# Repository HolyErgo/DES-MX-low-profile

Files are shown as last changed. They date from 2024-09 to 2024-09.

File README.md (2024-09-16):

# DES keycaps for MX low profile switches with legends

Based on honourable [@pseudoku](https://github.com/pseudoku/)'s [DES](https://github.com/pseudoku/PseudoMakeMeKeyCapProfiles)

Contains 3 rows (R2, R3, R4) and 3 keys for thumbs.
Row keys has tilted version for inner index column.

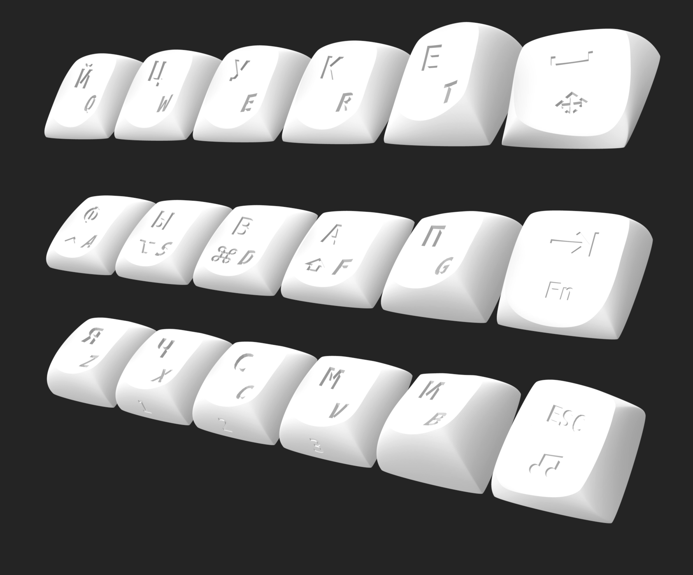
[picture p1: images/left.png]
Whole left side keycaps


### Fits switches:
- Gateron low profile V1 and V2 (KS-27 and KS-33)
- Nuphy low profile
- Keychron low profile optical
- Kailh Choc V2

## OpenSCAD sources

Source code is in `openscad` directory.

`key.scad` generates single keycap.

`generator.scad` contains legends presets for both halfs.

`make_left.scad` and `make_right.scad` generates keycaps in one STL for selected half. 

## How to
Before you start make sure OpenSCAD is up to date.

### Render one keycap
* open `key.scad` in OpenScad
* select keycap you want to render by changing KeyID in `keycap` call
* press F5 to review
* press F6 to render
* press F7 to export as STL

### Legends
If you want to render keycap without legend just set `Legends` parameter to `false`.

All matrix keycaps has defined positions for 2 legends:
1. In top left corner with fontsize 4
2. In bottom right corner with fontsize 3.5

All matrix keycaps except inner index column has 2 extra positions:
3. In bottom left corner with fontsize 3
4. In top right corner with fontsize 3
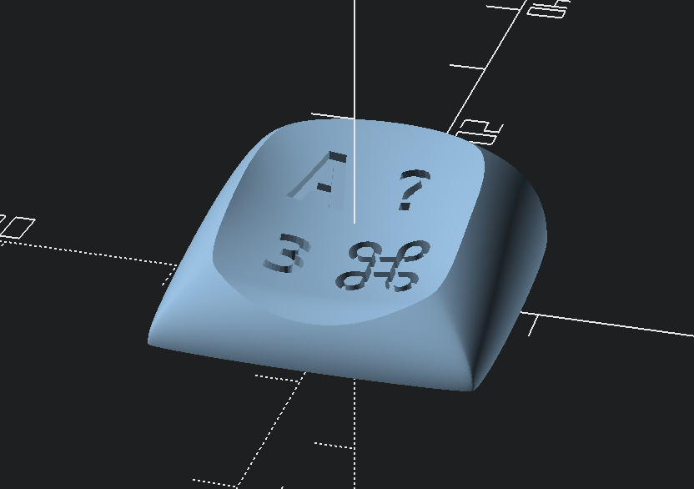
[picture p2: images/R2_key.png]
R2 keycap with 4 legends


Bottom row caps has one extra position on bottom cap side.
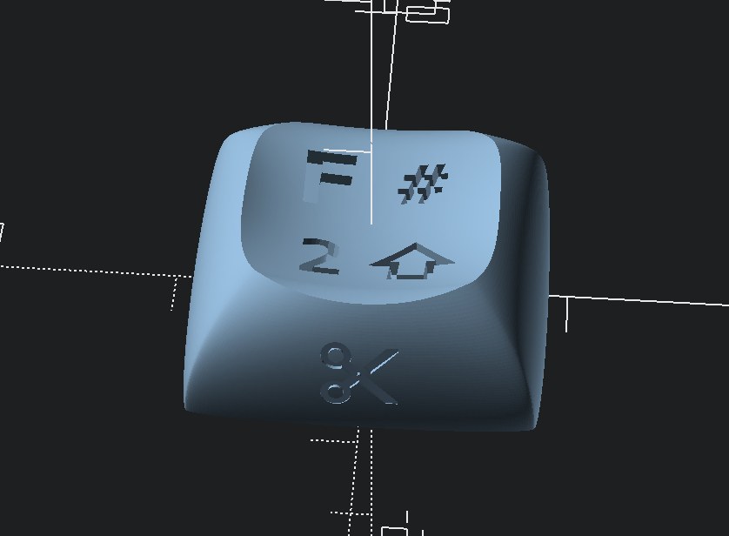
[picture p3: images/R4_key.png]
R4 keycap with 5 legends


Thumbs keycaps has 2 legend positions:
1. On top with fontsize 3
2. On bottom with fontsize 2.5
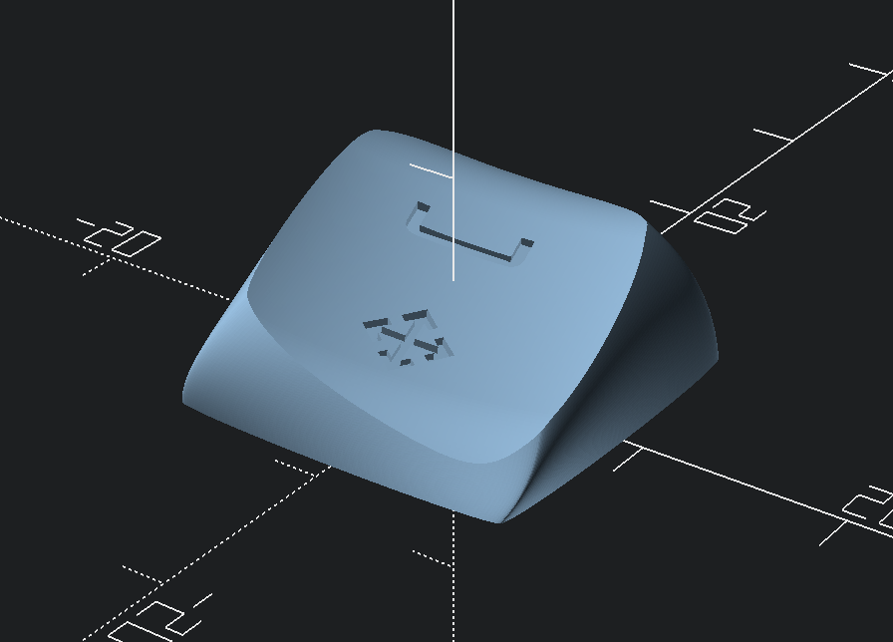
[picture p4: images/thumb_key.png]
Thumbs keycap with 2 legends


To render legends you have to pass them as array in `Legend` parameter. 
```
keycap(
  keyID  = 0, //set keycap
  cutLen = 0, //Don't change. for chopped caps
  Stem   = true, //turn on shell and stems
  Dish   = true, //turn on dish cut
  Stab   = 0, 
  visualizeDish = false, // turn on debug visual of Dish 
  crossSection  = false, // center cut to check internal
  homeDot = false, //turn on homedots
  Legends = ["A",  "command.svg", "3", "!"]
);

```

Each element of legends array may be a symbol, SVG filename or array. Use array as element if you need to specify font size for the legend.
```Legends = ["A", ["shift.svg", 5], ["?", 2.5]]```
You may use empty string for any element to reach next.
```Legends = ["A", "", "", ["?", 2.5]]```

SVG incons are stored in `symbols` directory. If you want to add icons do check paths in svg files. OpenSCAD can't close paths correctly so in some icons you need to do it manually.

Default font for legends is Menlo. It's shipped with MacOS since version 10.13. 

### Render whole half
To render all keycaps for keyboard half in one STL select a preset from `generator.scad` and put it to make-file `make_left.scad` or `make_right.scad`. For examle, to render caps for left half with English Qwerty legends:
```
use <generator.scad>

// Generates all keycaps for left part
generate_part(leftQuerty);
```

Generated STL is useful for resin print. Default parameters allows to print generated STL even on small printers like Elegoo Mars or Anycubic Photon Mono. 

You can change horizontal spacing with `horizontalPitch` variable.
Vertical spacing and X-axis rotation are set in `rows` array.

### Headless rendering
Rendering all keycaps may take a few hours. So a reasonable solution is to render them from command line.

Make sure you put correct preset to make-file before start. Then run rendering in terminal.

```
openscad -o left.stl make_left.scad
```

On Mac you can use full path to OpenSCAD:
```
/Applications/OpenSCAD.app/Contents/MacOS/openscad -o left.stl make_left.scad
```

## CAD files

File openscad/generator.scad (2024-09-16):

use <key.scad>

// 

test = [
  // keys by rows in left to right order
  // ID   Leg1  Leg2 
  [ // R2
    [ 3,   ["Й",  "Q"]],
  ],
  [
    [ 4,   ["Ц",  "W"]],
  ],
  [ // thumbs
    [ 5,   ["W",  "N"]],
  ],
];

/*
 * Preset for keycaps without legends
 */

leftNoLegends = [
  // keys by rows in left to right order
  // ID   Leg1  Leg2  Leg3  Leg4  Leg5
  [ // R2
    [ 0, false],
    [ 0, false],
    [ 0, false],
    [ 0, false],
    [ 3, false],
    [11, false], // inner thumbs
  ],
  [ // R3
    [ 1, false],
    [ 1, false],
    [ 1, false],
    [ 1, false],
    [ 4, false],
    [ 9, false], // home thumbs
  ],
  [ // R4
    [ 2, false],
    [ 2, false],
    [ 2, false],
    [ 2, false],
    [ 5, false],
    [10, false], // outer thumbs
  ],
];

rightNoLegends = [
  // keys by rows in left to right order
  // ID   Leg1  Leg2 
  [ // R2
    [ 6, false],
    [ 0, false],
    [ 0, false],
    [ 0, false],
    [ 0, false],
    [12, false], // outer thumbs
  ],
  [ // R3
    [ 7, false],
    [ 1, false],
    [ 1, false],
    [ 1, false],
    [ 1, false], 
    [ 9, false], // home thumbs
  ],
  [ // R4
    [ 8, false],
    [ 2, false],
    [ 2, false],
    [ 2, false],
    [ 2, false],
    [13, false], // inner thumbs
  ],
];


/*
 * Preset for English Qwerty layout
 * - english symbols are in top left corners of keycaps
 */

leftQuerty = [
  // keys by rows in left to right order
  // ID   Leg1  Leg2  Leg3  Leg4  Leg5
  [ // R2
    [ 0, ["Q"]],
    [ 0, ["W"]],
    [ 0, ["E"]],
    [ 0, ["R"]],
    [ 3, ["T"]],
    [11, [["space.svg", 5],  ["arrows.svg", 3.5]]], // inner thumbs
  ],
  [ // R3
    [ 1, ["A", "control.svg"]],
    [ 1, ["S", "option.svg"]],
    [ 1, ["D", "command.svg"]],
    [ 1, ["F", "shift.svg"]],
    [ 4, ["G"]],
    [ 9, [["tab.svg", 5],  "Fn"]], // home thumbs
  ],
  [ // R4
    [ 2, ["Z"]],
    [ 2, ["X",   "",   "",   "",  "1"]],
    [ 2, ["C",   "",   "",   "",  "2"]],
    [ 2, ["V",   "",   "",   "",  "3"]],
    [ 5, ["B"]],
    [10, [["ESC", 2.5],  ["media.svg", 3.5]]], // outer thumbs
  ],
];

rightQwerty = [
  // keys by rows in left to right order
  // ID   Leg1  Leg2 
  [ // R2
    [ 6, ["Y"]],
    [ 0, ["U"]],
    [ 0, ["I"]],
    [ 0, ["O"]],
    [ 0, ["P"]],
    [12, [["return.svg", 5],  ["#", 3.5]]], // outer thumbs
  ],
  [ // R3
    [ 7, ["H"]],
    [ 1, ["J", "shift.svg"]],
    [ 1, ["K", "command.svg"]],
    [ 1, ["L", "option.svg"]],
    [ 1, [";", "control.svg"]], 
    [ 9, [["shift.svg", 5],  ""]], // home thumbs
  ],
  [ // R4
    [ 8, ["N"]],
    [ 2, ["M",   "",   "",   "",  "paste.svg"]],
    [ 2, [",",   "",   "",   "",  "copy.svg"]],
    [ 2, [".",   "",   "",   "",  "cut.svg"]],
    [ 2, ["/"]],
    [13, [["backspace.svg", 5],  "123"]], // inner thumbs
  ],
];

/*
 * Preset for Russian and English layouts
 * - russian symbols are in top left corners
 * - english symbols in bottom right corners (Qwerty layout)
 */

leftRussianEnglishQuerty = [
  // keys by rows in left to right order
  // ID   Leg1  Leg2  Leg3  Leg4  Leg5
  [ // R2
    [ 0, ["Й",  "Q"]],
    [ 0, ["Ц",  "W"]],
    [ 0, ["У",  "E"]],
    [ 0, ["К",  "R"]],
    [ 3, ["Е",  "T"]],
    [11, [["space.svg", 5],  ["arrows.svg", 3.5]]], // inner thumbs
  ],
  [ // R3
    [ 1, ["Ф",  "A", "control.svg"]],
    [ 1, ["Ы",  "S", "option.svg"]],
    [ 1, ["В",  "D", "command.svg"]],
    [ 1, ["А",  "F", "shift.svg"]],
    [ 4, ["П",  "G"]],
    [ 9, [["tab.svg", 5],  "Fn"]], // home thumbs
  ],
  [ // R4
    [ 2, ["Я",  "Z"]],
    [ 2, ["Ч",  "X",   "",   "",  "1"]],
    [ 2, ["С",  "C",   "",   "",  "2"]],
    [ 2, ["М",  "V",   "",   "",  "3"]],
    [ 5, ["И",  "B"]],
    [10, [["ESC", 2.5],  ["media.svg", 3.5]]], // outer thumbs
  ],
];

rightRussianEnglishQuerty = [
  // keys by rows in left to right order
  // ID   Leg1  Leg2 
  [ // R2
    [ 6, ["Н",  "Y"]],
    [ 0, ["Г",  "U"]],
    [ 0, ["Ш",  "I"]],
    [ 0, ["Щ",  "O"]],
    [ 0, ["З",  "P"]],
    [12, [["return.svg", 5],  ["#", 3.5]]], // outer thumbs
  ],
  [ // R3
    [ 7, ["Р",  "H"]],
    [ 1, ["О",  "J", "shift.svg"]],
    [ 1, ["Л",  "K", "command.svg"]],
    [ 1, ["Д",  "L", "option.svg"]],
    [ 1, ["Ж",  ";", "control.svg"]], 
    [ 9, [["shift.svg", 5],  ""]], // home thumbs
  ],
  [ // R4
    [ 8, ["Т",  "N"]],
    [ 2, ["Ь",  "M", "", "", "paste.svg"]],
    [ 2, ["Б",  ",", "", "", "copy.svg"]],
    [ 2, ["Ю",  ".", "", "", "cut.svg"]],
    [ 2, [".",  "/"]],
    [13, [["backspace.svg", 5],  "123"]], // inner thumbs
  ],
];


horizontalPitch = 19; // distance between key centers

rows = [
// YOffset XRotate
  [     0,     -45],
  [    25,     -45],
  [    50,     -45],
];


// Generates keys for whole part
module generate_part(part) {
  for (row = [0:len(part)-1])
    for (key = [0:len(part[row])-1])
      translate([key * horizontalPitch, -rows[row][0], 0])
        rotate([rows[row][1], 0, 0])
  	      keycap(
            keyID  = part[row][key][0], 
            Legends = part[row][key][1],
            cutLen = 0, //Don't change. for chopped caps
            Stem   = true, //tusn on shell and stems
            Dish   = true, //turn on dish cut
            Stab   = 0, 
            visualizeDish = false, // turn on debug visual of Dish 
            crossSection  = false, // center cut to check internal
            homeDot = false, //turn on homedots
          );
}

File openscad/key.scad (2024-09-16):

use <libraries/scad-utils/morphology.scad> //for cheaper minwoski 
use <libraries/scad-utils/transformations.scad>
use <libraries/scad-utils/shapes.scad>
use <libraries/scad-utils/trajectory.scad>
use <libraries/scad-utils/trajectory_path.scad>
use <libraries/sweep.scad>
use <libraries/skin.scad>  

/*DES (Distorted Elliptical Saddle) Sculpted Profile for 6x3 and corne thumb 
Version 2: Eliptical Rectangle

*/
keycap(
  keyID  = 13, //change profile refer to KeyParameters Struct
  cutLen = 0, //Don't change. for chopped caps
  Stem   = true, //tusn on shell and stems
  Dish   = true, //turn on dish cut
  Stab   = 0, 
  visualizeDish = false, // turn on debug visual of Dish 
  crossSection  = false, // center cut to check internal
  homeDot = false, //turn on homedots
  Legends = ["ESC",  "tab", "command.svg"]
);

/*
translate([19,0,0])
keycap(
  keyID  = 11, //change profile refer to KeyParameters Struct
  cutLen = 0, //Don't change. for chopped caps
  Stem   = true, //tusn on shell and stems
  Dish   = true, //turn on dish cut
  Stab   = 0, 
  visualizeDish = false, // turn on debug visual of Dish 
  crossSection  = false, // center cut to check internal
  homeDot = false, //turn on homedots
  Legends = ["Cmd", "Space"]
);
/**/
//Parameters
wallthickness = 1.5; // 1.5 for norm, 1.25 for cast master
topthickness  = 2.9;   // 3 for norm, 2.5 for cast master
stepsize      = 60;  //resolution of Trajectory  больше - плавнее
step          = 1;   //resolution of ellipes     меньше - плавнее
fn            = 60;  //resolution of Rounded Rectangles: 60 for output, 16 for tests
layers        = 50;  //resolution of vertical Sweep: 50 for output, 40 for tests
dotRadius     = 0.55;   //home dot size
//---Stem param
Tol    =  0.0; // дополнительное расширение крестика в стэме
stemRot = 0;
stemWid = 7.55;
stemLen = 5.55 ;
stemCrossHeight = 4;
extra_vertical  = 0.6;
StemBrimDep     = -0.85; //торчание стема
stemLayers      = 50; //resolution of stem to cap top transition

baseFont = "Menlo:style=Bold";

keyParameters = //keyParameters[KeyID][ParameterID]
[
//  BotWid, BotLen, TWDif, TLDif, keyh, WSft, LSft  XSkew, YSkew, ZSkew, WEx, LEx, CapR0i, CapR0f, CapR1i, CapR1f, CapREx, StemEx
    // matrix
    [17.16,  17.16,   6.5, 	 6.5, 5.75,    0,    0,   -13,     0,     0,   2,   2,      1,      5,      1,    3.5,     2,       2], //R2 0
    [17.16,  17.16,   6.5, 	 6.5, 4.75,    0,   .5,     4,     0,     0,   2,   2,      1,      5,      1,    3.5,     2,       2], //R3 1
    [17.16,  17.16,   6.5, 	 6.5, 6.55,    0,    0,     9,     0,     0,   2,   2,      1,      5,      1,    3.5,     2,       2], //R4 2
    
    // inner index column left
    [17.16,  17.16,   6.5, 	 6.5, 7.75,    0,    0,   -16,    12,     0,   2,   2,      1,      5,      1,    3.5,     2,       2], //R2 3
    [17.16,  17.16,   6.5, 	 6.5, 6.75,    0,   .5,     4,    12,     0,   2,   2,      1,      5,      1,    3.5,     2,       2], //R3 4
    [17.16,  17.16,   6.5, 	 6.5, 8.55,    0,    0,    18,    12,     0,   2,   2,      1,      5,      1,    3.5,     2,       2], //R4 5
    
    // inner index column right
    [17.16,  17.16,   6.5, 	 6.5, 7.75,    0,    0,   -16,   -12,     0,   2,   2,      1,      5,      1,    3.5,     2,       2], //R2 6
    [17.16,  17.16,   6.5, 	 6.5, 6.75,    0,   .5,     4,   -12,     0,   2,   2,      1,      5,      1,    3.5,     2,       2], //R3 7
    [17.16,  17.16,   6.5, 	 6.5, 8.55,    0,    0,    18,   -12,     0,   2,   2,      1,      5,      1,    3.5,     2,       2], //R4 8

    // thumb center
    [17.16,  17.16,     4,     5,   6,    0,    0,    -12,     0,     0,   2,   2,      1,      5,      1,      3,     2,       2], //center 10

    // thumb left
    [17.16,  17.16,     4, 	   6,   7,    0,    0,    -12,    10,    15,   2,   2,      1,      5,      1,      2,     2,       2], //outer  9  
    [17.16,  17.16,     4, 	   5, 5.5,    0,    0,     -8,    -5,   -15,   2,   2,      1,   4.85,      1,      3,     2,       2], //inner  11

    // thumb right
    [17.16,  17.16,     4, 	   6,   7,    0,    0,    -12,   -10,   -15,   2,   2,      1,      5,      1,      2,     2,       2], //outer  12 
    [17.16,  17.16,     4, 	   5, 5.5,    0,    0,     -8,     5,    15,   2,   2,      1,   4.85,      1,      3,     2,       2], //inner  14
];


dishParameters = //dishParameter[keyID][ParameteID]
[ 
//FFwd1 FFwd2 FPit1 FPit2  DshDep DshHDif FArcIn FArcFn FArcEx     BFwd1 BFwd2 BPit1 BPit2  BArcIn BArcFn BArcEx
  // matrix
  [ 6.5,    3,   10,  -50,      5,    1.8,   8.8,    15,     2,        6,    4,   13,   30,    8.8,    16,     2], //R2
  [   6,    3,   10,  -55,      5,    1.8,   8.5,    15,     2,        6,  3.7,   10,  -55,    8.5,    15,     2], //R3
  [   6,    3,   18,  -50,      5,    1.8,   8.8,    15,     2,      5.5,  4.4,    5,  -55,    8.8,    15,     2], //R4
  
  // inner index column left
  [ 6.5,    3,   10,  -50,      5,    1.9,   8.8,    15,     2,        6,    4,   13,   30,    8.8,    16,     2], //R2
  [   6,    3,   10,  -55,      5,    1.8,   8.9,    15,     2,        6,  3.7,   10,  -55,    8.9,    15,     2], //R3
  [   6,    3,   18,  -50,      5,    1.8,   9.2,    15,     2,      5.8,  4.4,    5,  -55,    9.2,    15,     2], //R4
  
  // inner index column right
  [ 6.5,    3,   10,  -50,      5,    1.9,   8.8,    15,     2,        6,    4,   13,   30,    8.8,    16,     2], //R2
  [   6,    3,   10,  -55,      5,    1.8,   8.9,    15,     2,        6,  3.7,   10,  -55,    8.9,    15,     2], //R3
  [   6,    3,   18,  -50,      5,    1.8,   9.2,    15,     2,      5.8,  4.4,    5,  -55,    9.2,    15,     2], //R4
  
  // thumbs center
  [   6,  4.8,    5,  -48,      5,    2.2,  10.5,    10,     2,        6,    4,    0,  -30,   10.5,    18,     2], //center

  // thumb left
  [ 6.5,  4.8,    5,  -48,      4,    2.0,    11,    12,     2,        5,    4,    5,  -48,     11,    12,     2], //outer
  [ 6.5,  4.8,    5,  -48,      4,    2.0,   9.5,    10,     2,       10,    4,   13,  -30,    9.5,    20,     2], //inner
  
  // thumb right
  [ 6.5,  4.8,    5,  -48,      4,    2.0,    11,    12,     2,        5,    4,    5,  -48,     11,    12,     2], //outer
  [ 6.5,  4.8,    5,  -48,      4,    2.0,   9.5,    10,     2,       10,    4,   13,  -30,    9.5,    20,     2], //inner
];

legendParameters = //legendParameter[keyID][ParameteID]
[ 
//   XSkeAdj YSkeAdj ZSkeAdj XOffs YOffs   HAdj  FntSz      Font
  // matrix
  [ // 0 R2
    [      5,      8,      0,   -3,    4,  -2.8,     4, baseFont],
    [     -5,     -8,      0,    3,   -3,  -2.8,   3.5, baseFont],
    [     -5,      8,      0,   -3,   -3,  -2.8,     3, baseFont],
    [      5,     -8,      0,    3,    4,  -2.8,     3, baseFont],
  ], 
  [ // 1 R3
    [      3,      9,      0,   -3,  2.5,  -2.5,     4, baseFont],
    [     -3,     -8,      0,    3, -4.5,  -2.7,   3.5, baseFont],
    [     -3,      8,      0,   -3, -4.5,  -2.7,     3, baseFont],
    [      3,     -9,      0,    3,  2.5,  -2.5,     3, baseFont],
  ], 
  [ // 2 R4
    [      1,      8,      0,   -3,  2.5,  -2.8,     4, baseFont],
    [     -8,     -8,      0,    3, -4.5,  -3.1,   3.5, baseFont],
    [     -8,      8,      0,   -3, -4.5,  -3.1,     3, baseFont],
    [      1,     -8,      0,    3,  2.5,  -2.8,     3, baseFont],
    [     85,      0,      0,    0,  1.3,   2.5,     3, baseFont],
  ], 
  
  // inner index column left
  [ // 3 R2
    [      3,    -14,      0, -2.5,  4.5,  -3.0,     4, baseFont],
    [     -5,    -31,      0,    4,   -3,  -3.2,   3.5, baseFont],
  ], 
  [ // 4 R3
    [      3,    -14,      0, -2.5,  2.5,  -2.8,     4, baseFont],
    [     -4,    -32,      0,    4, -4.5,  -3.1,   3.5, baseFont],
  ], 
  [ // 5 R4
    [      2,    -14,      0, -2.5,    2,  -2.9,     4, baseFont],
    [     -8,    -32,      0,  4.5, -5.5,  -3.7,   3.5, baseFont],
  ], 
  
  // inner index column right
  [ // 6 R2
    [      5,     31,      0, -4.5,  4.5,  -3.4,     4, baseFont],
    [     -5,     14,      0,    2,   -3,  -3.0,   3.5, baseFont],
  ], 
  [ // 7 R3
    [      3,     32,      0, -4.5,  2.5,  -2.9,     4, baseFont],
    [     -4,     15,      0,    2, -4.5,  -2.9,   3.5, baseFont],
  ], 
  [ // 8 R4
    [      2,     32,      0, -4.5,    2,  -3.3,     4, baseFont],
    [     -8,     15,      0,  2.5, -5.5,  -3.5,   3.5, baseFont],
  ], 
  
  [ // 9 thumb center
    [     -1,      0,      0,    0,    4,  -2.5,     3, baseFont],
    [     -3,      0,      0,    0, -3.5,  -2.6,   2.5, baseFont],
  ],
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

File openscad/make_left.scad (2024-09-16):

use <generator.scad>

// Generates all keycaps for left part
generate_part(left);

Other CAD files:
openscad/make_right.scad
openscad/make_test.scad

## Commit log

2024-01-19 MX low profile set
    [Choc_Chicago_Steno.scad, Choc_Chicago_Steno_Convex.scad, Choc_Chicago_Steno_Thumb.scad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]
2024-09-16 Generator with legends presets - generates full keycaps set for keyboard half - optimized for resin print
    [R2-left.stl, R2-plain.stl, R3-left.stl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]
